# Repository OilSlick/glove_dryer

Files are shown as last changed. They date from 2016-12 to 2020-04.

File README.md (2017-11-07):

This project uses an Arduino Uno to read relative humidity from two sensors; one inside a glove and another outside the glove. Based on the difference of the two values, it runs a number of PC fans to move wetter air out of the gloves and drier air into the gloves. 

### Basic Operation

1. Check relative humidity (RH) at both sensors
2. Start a running average (RA) of the difference between the two to correlate*
3. If the correlated values differ by >= 3%, turn on fans for 30 minutes
4. Recheck humidity.
 
### To-Do
* [x] ~~Switch FANCONTINUOUS to use millis instead of delay~~ (decided against FANCONTINUOUS)
* [x] Have fan-to-PVC pipe bracket printed 3D
* [x] ~~Enable power-save for Arduino~~ (June 1, 2017: removed power-saving code)
* [x] ~~Put LCD on PWM pin and power up/down as needed~~ (removed LCD)
 * [x] Utilize IfSerial
* [x] ~~Power Arduino with [PowerBoost 1000 Charger](https://www.adafruit.com/products/2465)~~ (used OKI-78SR with 12v wall plug)
* [x] ~~Have Arduino case~~ and pipe-supports printed 3D (test print proved the box would be prohibitively expensive. Pipe supports work great)
* [x] Complete box (~~using old moo card box~~ Used plastic box from Muji)
* [x] Final assembly of fan posts
* [x] Add a momentary switch ~~for manual correlation~~ (added a toggle switch + timer to manually run dryer)
* [ ] Consider ways to re-correlate after a period of time (maybe after X cycles of fanoff?)
* [ ] Update schematics!!

*I am using two DHT11 humidity sensors and they tend to be roughly 2 percentage points off from one another, so I do a series of tests to see what the difference is between the two then apply that value to create a correlated value to compensate for the difference.

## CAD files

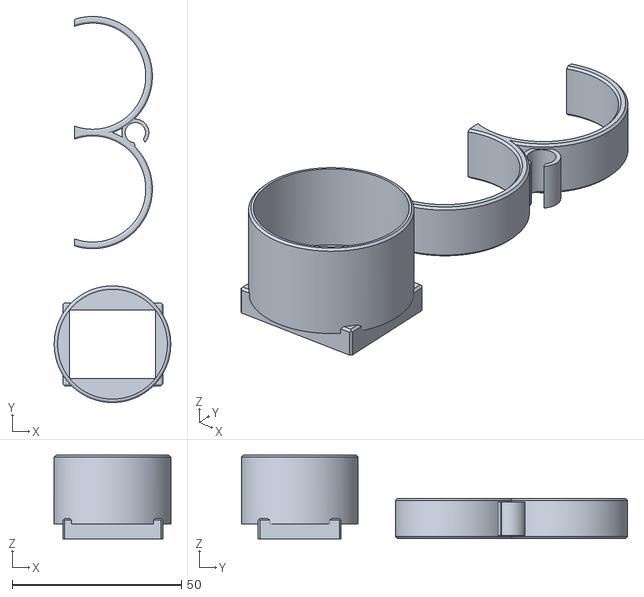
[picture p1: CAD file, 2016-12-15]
schematics/glove_dryer_fittings.stl
34.5 x 114.1 x 24.7

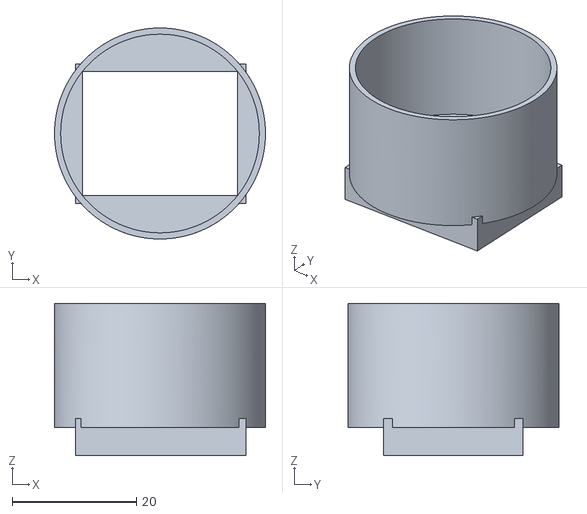
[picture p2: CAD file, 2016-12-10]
schematics/blower_32mmpipe_adapter.stl
34.0 x 34.0 x 24.6

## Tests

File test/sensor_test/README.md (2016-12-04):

# sensor_test

The first temp/humi sensor I bought was the [Grove - Temperature&Humidity Sensor (High-Accuracy &Mini) v1.0](http://wiki.seeed.cc/Grove-TemptureAndHumidity_Sensor-High-Accuracy_AndMini-v1.0/). Then I decided I wanted a second sensor to read relative humidity outside of the gloves, in order to bring the inside RH down to the outside RH, rather than some arbitrary RH value.fasfda

The second sensor I bought was the cheaper [Grove - Temp&Humi Sensor](https://www.seeedstudio.com/Grove-Temp%26amp%3BHumi-Sensor-p-745.html), which I later found tends to have [calibration issues](https://forum.arduino.cc/index.php?topic=96470.0). 

So I put together this sketch to see how far apart the two sensors are. Since I don't need hyper-accurate readings for this project, the thought is to keep a running average of the difference in RH and calibrate the two programatically using the running average.

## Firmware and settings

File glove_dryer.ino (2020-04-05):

/*
 *Board: Arduino Genuino Uno
 *Sensors: DHT11
 *Button: Adafruit Standalone Toggle Capacitive Touch Sensor Breakout - AT42QT1012
*/

#include "DHT.h"                            //Permits DHT usage
#include "RunningAverage.h"                 //Calculates running average for sensor correlation.
#include <SPI.h>
#ifdef __AVR__
  #include <avr/power.h>
#endif

//Running average vars
RunningAverage myRA(10);

//For RGB LED
const int TIP120pin = 5;                    //Base pin of TIP120 transistor
const int redLED = 9;
const int greenLED = 10;
const int blueLED = 11;
const int buttonpin = 12;                   //Output of capacitive touch switch
bool buttonPressed = 0;                     //track if button was pressed

int humidityOUT = 0;                        //Humidity outside of glove
int humidityGLOVE = 0;                      //Humidity inside of glove
int humidityOUTcorrelated = 0;              //Correlated DHT value
int humidityDIFF = 0;                       //Difference between DHT11 sensors
int humidityBaseline = 0;                   //Used to track current humidity VS when button pushed
char dhtOutStatus;
char dhtGloveStatus;                        

bool FANON = 0;                             //Track fan state
bool DEBUG = 0;                             //Set to "1" to initiate debug routine
bool sensorFail = 0;                        //Set to "1" if either sensor fails
bool OutSensorFail = 0;                     //Set to 1 if sensor fail
bool GloveSensorFail = 0;                   //Set to 1 if sensor fail
volatile unsigned long lastOnTime;          //Record the time fan turned on
int long onDuration = (1800000);            //Time in millis to leave fan on (1800000 = 30m)

DHT dhtGlove;
DHT dhtOut;

void setup()
{
  pinMode(TIP120pin, OUTPUT);
  pinMode(buttonpin, INPUT);
  
  //For RGB LED
  pinMode(redLED, OUTPUT);
  pinMode(greenLED, OUTPUT);
  pinMode(blueLED, OUTPUT);
  analogWrite(redLED, 255);
  analogWrite(greenLED, 255);
  analogWrite(blueLED, 255);
  
  //DHT sensor setup
  dhtGlove.setup(A0);
  dhtOut.setup(A1);

  Serial.begin(9600);                         // start serial for output

  myRA.clear(); // explicitly start RA clean

  
  Serial.println("Beginning sensor correlation");
  correlateSensors();

    if ( dhtGlove.getStatusString() == "OK" )
  {
    Serial.println("glove sensor OK");
  }
  else 
  {
    sensorFail = 1;
    GloveSensorFail = 1;
    Serial.println("glove sensor FAIL");
    LEDblinkRed();
  }
  if ( dhtOut.getStatusString() == "OK" )
  {
    Serial.println("room sensor OK");
  }
  else 
  {
    sensorFail = 1;
    OutSensorFail = 1;
    Serial.println("room sensor FAIL");
    LEDblinkRed();
  }
    Serial.println("Ready");
}
 
void loop()
{ 
  if ( dhtGlove.getStatusString() == "TIMEOUT" )
  {
    sensorFail = 1;
    GloveSensorFail = 1;
  }
  if ( dhtOut.getStatusString() == "TIMEOUT" )
  {
    sensorFail = 1;
    OutSensorFail = 1;
  }
  if ( sensorFail == 1 && FANON == 0 )
  {
    LEDfadeYellow();
  }
  if ( digitalRead(buttonpin) == HIGH && FANON == 0 && buttonPressed == 0 ) //detect state change
  {
    buttonPressed = 1;
    
    if ( Serial )
    {
      DISPLAYSERIAL();
    }
    turnfanon();
    if ( lastOnTime == 0 )
    {
      lastOnTime = millis();
    }
    if ( humidityBaseline == 0 ) 
    {
      humidityBaseline = humidityOUT;
    }
  }
  if ( digitalRead(buttonpin) == LOW && buttonPressed == 1 ) //detect state change
  {
    buttonPressed = 0;
    /*if ( FANON == 1 )
    {
      turnfanoff();
    } */
  }
  if ( FANON == 1 )
  {
    LEDfadeBlue();
    readSensors();
   if ( millis() >= (lastOnTime + onDuration) )
    {
      if ( sensorFail == 0 )
      {
        //Leave fans on but reset timer and re-evaluate status
        lastOnTime = millis();
      }
      else 
      {
        if ( humidityBaseline > humidityOUT ) //if the room humidity is dropping since turning on fan
        {
          humidityBaseline = humidityOUT;
          lastOnTime = millis();            //extend ontime by onDuration
          Serial.println("Resetting timer. Extending fantime");
        }
        else if ( humidityOUT < 60 )  //if the button pressed and AC is on (low RH) keep fan on
        {
          lastOnTime = millis();
        }
        else 
        {
          turnfanoff(); // Fan off
          LEDfadeGreen();
        }
      }                        
    }
  }
  else 
  {
    turnfanoff(); // Fan off
    if ( sensorFail != 1 )
    {
      LEDfadeGreen();
    }
    if ( sensorFail == 1 )
    {
      LEDfadeYellow();
    }
    readSensors();
  }

  //Trigger events based on difference in humidity levels
  if ( humidityGLOVE >= (humidityOUTcorrelated + 3) && sensorFail != 1 )  
  {
    if ( Serial )
    {
      DISPLAYSERIAL();
    }
    turnfanon();
    lastOnTime = millis();
  }
  else if ( humidityGLOVE <= (humidityOUTcorrelated + 2) && FANON == 1 && (digitalRead(buttonpin) == LOW) && sensorFail != 1 )
  //if the two sensors are close enough, the fan is already on, and the button isn't active, turn fan off
  //if the button is on, over-ride sensors and stay on. 
  {
    if ( Serial )
    {
      DISPLAYSERIAL();
    }
    turnfanoff();
    lastOnTime = 0;                         //Reset timer
  }
  /*else if ( FANON == 1 && (digitalRead(buttonpin) == LOW) && sensorFail == 1 )
  {
    if ( Serial )
    {
      DISPLAYSERIAL();
    }
    turnfanoff();
    lastOnTime = 0;                         //Reset timer
    humidityBaseline = 0;                   //Reset baseline
  }*/
  else
  {
    if ( Serial )
    {
      DISPLAYSERIAL();
    }
  }
  delay(dhtGlove.getMinimumSamplingPeriod()); //play nice with DHT sensor
} 

//FUNCTIONS

void turnfanon()
{
  analogWrite(TIP120pin, 255);
  FANON = 1;
}
void turnfanoff()
{
  analogWrite(TIP120pin, 0);
  FANON = 0;
  lastOnTime = 0;                         //Reset timer
  humidityBaseline = 0;                   //Reset baseline
}
void LEDblinkRed()
{
  setColor(255, 0, 0);  // Red
  delay(50);
  setColor(0, 0, 0);      // no LED
  delay(50);
  setColor(255, 0, 0);  // Red
  delay(50);
  setColor(0, 0, 0);      // no LED
}

void readSensors()
{
  humidityGLOVE = dhtGlove.getHumidity();
  humidityOUT = dhtOut.getHumidity();
  humidityDIFF = humidityGLOVE - humidityOUT;
  humidityOUTcorrelated = humidityOUT + myRA.getAverage();
}
void DISPLAYSERIAL()
{
  Serial.print("Glove Humidity: ");
  Serial.print(humidityGLOVE);
  Serial.print("%");
  Serial.print("\t Raw Room Humidity: ");
  Serial.print(humidityOUT);
  Serial.print("%");
  Serial.print("\t Correlated Room Humidity: ");
  Serial.print(humidityOUTcorrelated);
  Serial.print("\t Running Average: ");
  Serial.println(myRA.getAverage(), 3);
  Serial.print("DHT-Glove Status: ");
  Serial.print(dhtGlove.getStatusString());
  Serial.print("\t DHT-Out Status: ");
  Serial.print(dhtOut.getStatusString());
  Serial.print("\t DHT Delay ");
  Serial.println(dhtGlove.getMinimumSamplingPeriod());
  Serial.print("Fan Status: ");
  if ( FANON == 1)
  {
    Serial.println("ON");
  }
  else 
  {
    Serial.println("OFF");
  }
  Serial.print("sensorFail: ");
  Serial.println( sensorFail );
  Serial.print("humidityBaseline: ");
  Serial.println(humidityBaseline);
  Serial.print("lastOnTime: ");
  Serial.println(lastOnTime);
  Serial.print("Current millis: ");
  Serial.println( millis() );
  if ( FANON == 1)
  {
    Serial.print("Next eval: ");
    Serial.println( lastOnTime + onDuration );
  }
}

void correlateSensors()
{
  while (millis() < 11000)
  {
    humidityGLOVE = dhtGlove.getHumidity();
    humidityOUT = dhtOut.getHumidity();
    humidityDIFF = humidityGLOVE - humidityOUT;
    humidityOUTcorrelated = humidityOUT + myRA.getAverage();

  if ( Serial ) {
    Serial.print("Millis: ");
    Serial.println(millis());
    Serial.print("DHT Glove: ");
    Serial.print(humidityGLOVE);
    Serial.print("\t DHT Out: ");
    Serial.print(humidityOUT);
    Serial.print("\t Diff: ");
    Serial.println(humidityDIFF);
    Serial.print("Correlated Room Humidity: ");
    Serial.println(humidityOUTcorrelated);
  }

  //Blink LED
  setColor(64, 32, 0);  // Yellow
  delay(50);
  setColor(0, 0, 0);      // no LED
  delay(50);
  setColor(64, 32, 0);  // Yellow
  delay(50);
  setColor(0, 0, 0);      // no LED

  myRA.addValue(humidityDIFF);        //Add diff to running average

  delay(dhtGlove.getMinimumSamplingPeriod()); //play nice with DHT sensor
  }
}

void setColor(int red, int green, int blue)
{
  analogWrite(redLED, 255-red);
  analogWrite(greenLED, 255-green);
  analogWrite(blueLED, 255-blue);  
}

void LEDfadeGreen()
{
      //Fade in
    for (int fadeValue = 0 ; fadeValue <= 16; fadeValue += 1) {
    // sets the value (range from 0 to 255):
    setColor(0, fadeValue, 0); 
    // wait for 30 milliseconds to see the dimming effect
    delay(30);
  }

  //Fade out
  for (int fadeValue = 16 ; fadeValue >= 0; fadeValue -= 1) {
    // sets the value (range from 0 to 255):
    setColor(0, fadeValue, 0);  
    // wait for 30 milliseconds to see the dimming effect
    delay(30);
  }
}

void LEDfadeBlue()
{
      //Fade in
    for (int fadeValue = 0 ; fadeValue <= 16; fadeValue += 1) {
    // sets the value (range from 0 to 255):
    setColor(0, 0, fadeValue); 
    // wait for 30 milliseconds to see the dimming effect
    delay(30);
  }

  //Fade out
  for (int fadeValue = 16 ; fadeValue >= 0; fadeValue -= 1) {
    // sets the value (range from 0 to 255):
    setColor(0, 0, fadeValue); 
    // wait for 30 milliseconds to see the dimming effect
    delay(30);
  }
}

void LEDfadeYellow()
{
      //Fade in
    for (int fadeValue = 0 ; fadeValue <= 16; fadeValue += 1) {
    // sets the value (range from 0 to 255):
    setColor(fadeValue + 32, fadeValue, 0); 
    // wait for 30 milliseconds to see the dimming effect
    delay(30);
  }

  //Fade out
  for (int fadeValue = 16 ; fadeValue >= 0; fadeValue -= 1) {
    // sets the value (range from 0 to 255):
    setColor(fadeValue, fadeValue, 0); 
    // wait for 30 milliseconds to see the dimming effect
    delay(30);
  }
}

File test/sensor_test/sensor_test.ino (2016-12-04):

// DHT readings made simple by Mark Ruys:
// https://github.com/markruys/arduino-DHT
// Running averages made simple by Rob Tillaart:
// https://github.com/RobTillaart/Arduino/tree/master/libraries/RunningAverage

#include "DHT.h"
#include "TH02_dev.h"
#include "RunningAverage.h"

RunningAverage myRA(10);
int samples = 0;
int humidity = 0;
int cycle = 0;
float previousRA = 0;

DHT dht;

void setup()
{
  Serial.begin(9600);

  dht.setup(A0);
  
  //Temp+humid requirements
  Serial.println("****THO2 power up delay, letting voltage settle****\n");
  /* Power up,delay 150ms,until voltage is stable */
  delay(150);
  /* Reset HP20x_dev */
  TH02.begin();
  delay(100);
  
  /* Determine TH02_dev is available or not */
  Serial.println("TH02_dev is available.\n"); 

  myRA.clear(); // explicitly start RA clean
}

void loop()
{
  delay(dht.getMinimumSamplingPeriod());

  int humidityDHT = dht.getHumidity();
  int humidityGLOVE = TH02.ReadHumidity();
  int humidityDIFF = humidityGLOVE - humidityDHT;
  
  Serial.print("DHT humdity = ");
  Serial.print(humidityDHT);

  Serial.print("\t Top Humidity: ");
  Serial.print(humidityGLOVE);

  Serial.print("\t Difference: ");
  Serial.print(humidityDIFF);

  myRA.addValue(humidityDIFF);
  samples++;
  Serial.print("\t Running Average: ");
  Serial.print(myRA.getAverage(), 3);
  Serial.print("\t Samples: ");
  Serial.println(samples);

  Serial.print("Minimum RA: ");
  Serial.print(myRA.getMin(), 3);
  Serial.print("\t Maximum RA: ");
  Serial.print(myRA.getMax(), 3);
  Serial.print("\t Cycle Count: ");
  Serial.print(cycle);

  Serial.print("\t Previous RA: ");
  Serial.println(previousRA);

  if (samples == 300)
  {
    previousRA=myRA.getAverage();
    cycle++;
    samples = 0;
    myRA.clear();
    Serial.print("Cycles: ");
    Serial.print(cycle);
  }
  delay(10);

}

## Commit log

2016-12-03 repo creation
    creating repo from existing, local work
    [glove_dryer.fzz]
2016-12-04 count cycles
    The running average is reset every 300 loops. No the sketch also counts
    cycles of 300 loops.
    [sensor_test.ino]
2016-12-04 created readme for sensor_test
2016-12-04 Add DHT sensor readings
    Begin adding DHT functions by reading the sensor and outputting to
    serial.
2016-12-04 Add running average functionality
    developed in sensor_test.ino then ported over to glove_dryer.ino. Will
    eventually add to conditionals for when to activate fan.
2016-12-04 Added DHT calibration functionality
    Changed all humidityGLOVE vars to integers and also added calibration
    routine.
2016-12-04 Added calibrated RH to conditional
    Fan turns on if glove RH is 3%+ higher than calibrated outside RH. BAM!
2016-12-05 new function for using calibrated data
    Created USECALIBRATEDHUMI();
2016-12-05 revert to humidity levels
    Calibration of DHT is posing too much of a problem...maybe I can
    calibrate first.
    [glove_dryer.ino]
2016-12-07 correlate sensors in setup
    Also added function for serial display to reduce number of lines
2016-12-07 changed verbiage to "correlate"
    Also removed USECALIBRATEDHUMI() function, as I correlate the sensors
    once in setup now.
2016-12-10 Ditching the battery-eating OLED display
    Also added fan adapter 3d file. Haven't verified it yet. Just having it
    printed.
    [blower_32mmpipe_adapter.stl]
2016-12-15 Added STL version of working adapters
    [glove_dryer_fittings.stl]
2017-01-11 removed button circuit
2017-01-11 replace TH02 with DHT11
    TH02 sensor over-complicated things. I replaced it with another DHT11
    sensor, which reads close enough to the original to make it more
    convenient.
    [glove_dryer.ino]
2017-01-11 Added neopixels
    Also switched to "powerdown," which drops current to ~20mA from ~40mA.
2017-05-27 add green LED function & remove power nap
2017-05-27 brighten LED
2017-09-06 see description
    - wasn't reading sensors while fans on
    - wasn't evaluating sensors while fans on
    - created method to read sensors to reduce # of code lines
2017-11-01 documented replacement of 7805 regulator with OKI-78SR
2017-11-07 replaced 'while' loop with an 'if' statement and testing cap switch
    [glove_dryer.ino]
2017-11-07 fade LED in and out
2017-11-07 return 30min cycles, clean up code
    removed unused function and renamed the LED fading functions to fit in
    with other naming conventions used.
2019-12-03 better drying with just button pressed
    With a glove sensor fail, now it will dry for a period with just the button pressed. New conditions:
    RH < 60 = keep fans on controlled by switch timer
    RH dropping = keep fans on (assuming AC is on)
    [glove_dryer.ino]
